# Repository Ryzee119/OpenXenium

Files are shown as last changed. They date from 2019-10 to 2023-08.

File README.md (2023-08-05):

# OpenXenium
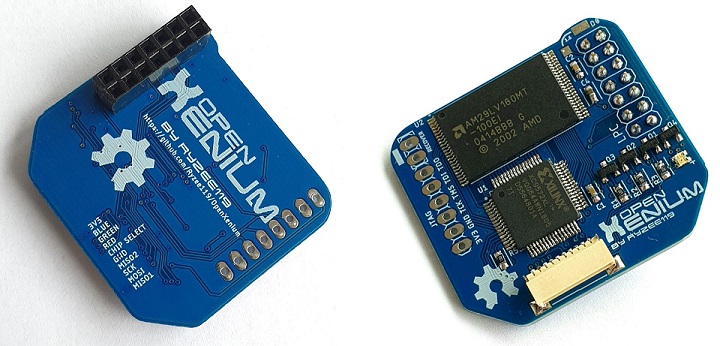
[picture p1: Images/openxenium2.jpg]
OpenXenium Assembled

## About this Repository
This is an open source recreation of an Original Xbox LPC memory/IO device. Generally known as a *modchip*.
The VHDL is 100% compatible with XeniumOS, which is a legal non-Microsoft based bootloader made by TeamXodus for the Original Xbox. This allows loading user BIOS binaries and some basic Xbox tools (EEPROM Backup/modification, Hard drive Rebuilding, Locking, Unlocking, FTP access).  
  
The VHDL written by Team Xodus was never released and the CPLD is read protected so it is not trivial to extract the bitstream.
My own VHDL is probably quite similar to what Team Xodus produced for the Xenium Modchip but I have independently reverse engineered the behavioral design on the CPLD. (There was no bypassing of the protection features of a genuine Xenium.) Therefore I have named this project **OpenXenium**. *An open source recreation of the Xenium CPLD released under GPL which documents the internal workings by means of open source VHDL of the Xenium Modchip*.

I do a quick run through of the build process here: https://youtu.be/P6YYViKby74

To manage your OpenXenium device's flash memory, the Xenium-Tools homebrew program has been moved [here](https://github.com/Ryzee119/Xenium-Tools).

## Supported Features
The VHDL implements the following LPC transactions:
  * Memory Read/Writes (Translated to a parallel flash memory interface)
  * IO Read/Writes

From an Original Xbox perspective, this covers all requirements to make a custom LPC memory/IO peripheral for the console. Colloquially known as a *modchip* which can load custom BIOS files like Cromwell and its derivatives without modifying the onboard TSOP flash memory or softmodding. This supports IO control for accessories like LCD screens, LED controllers, external switches etc.

When used with XeniumOS the VHDL in this repo supports the following features:
  * Software controlled BIOS bank switching (any BIOS combinations that fit into 1mbyte of flash memory (4x256k, 1x512+2x256k, 2x512k, 1x1mbyte).
  * Instant boot to a chosen BIOS using the power button.
  * Boot the XeniumOS with eject button.
  * Ability to boot from the onboard BIOS (colloquially known as TSOP booting). This will completely disable OpenXenium and release D0/LFRAME(1.6) to boot the Xbox as if stock.
  * All the standard features in XeniumOS. (EEPROM tools, Hard drive tools, FTP/SMB Server etc.).
  * Three general purpose outputs. These are normally bitbanged as a SPI master (MOSI,CLK,CS) with the most common use an LCD, however could support any SPI peripheral in theory.
  * Two general purpose inputs. On a Xenium, these are I believe intended to be MISO lines to complement the SPI interface but could be used for any 3.3V digital logic.  
  * Three outputs are connected to an RGB led (Or an external user added RGB led).
  * Reserved memory on the flash chip for non-volatile storage of an EEPROM backup and XeniumOS settings.
  * If you bridge the two recovery pins on power up, it will attempt to boot the XeniumOS recovery BIOS if available. This functions the same as a genuine Xenium modchip.
  * I also simulate the LFRAME abort mechanism (*Ref Intel LPC Interface Spec Rev 1.1 Section 4.2.1.13*) so that this will work on a v1.6 Original Xbox. This aborts the LPC transaction to prevent the Xyclops responding to the MCPX LPC Memory Read requests during boot (and conflicting with an external LPC memory peripheral). This is generally accepted to be better than shorting LFRAME the ground constantly which some traditional *Modchips* do.

## XeniumOS BIOS
**The recommended way to get a copy of XeniumOS is to take a backup of your own Xenium modchip using [Xenium-Tools](https://github.com/Ryzee119/Xenium-Tools/releases).** It is also possible to parse the v2.3.1 XeniumOS update files released by Team Xodus to extract the neccessary data; however this will not contain the factory programmed recovery sector, but otherwise works in the same way.

This has been tested with XeniumOS 2.3.1 (Last release) and XeniumOS 2.3.1(Gold variant). The only way to obtain Gold OS is to dump the flash contents of your XeniumGold as the binary files were never distributed individually.

## Installation and Initial Setup
See [Installation.MD](https://github.com/Ryzee119/OpenXenium/blob/master/INSTALLATION.md)
## Licensing
OpenXenium is free and open source. Please respect the licenses available in their respective folders.
  *  Hardware is shared under the [CERN OHL version 1.2.](https://ohwr.org/cernohl).
  *  Firmware is shared under [GPLv3](https://www.gnu.org/licenses/quick-guide-gplv3.en.html).
  *  xenium-tools was made with [NXDK](https://github.com/XboxDev/nxdk) and is shared under [GPLv2](https://www.gnu.org/licenses/old-licenses/gpl-2.0.en.html).
## References that helped me in this project
  * [Intel LPC Spec](https://www.intel.com/content/dam/www/program/design/us/en/documents/low-pin-count-interface-specification.pdf)
  *  [NXDK](https://github.com/XboxDev/nxdk)  
  * [AladdinLCD  Github Repo (CPLD LCD Driver)](https://github.com/Ryzee119/AladdinLCD)
  * [LPC Analyser Plugin](https://github.com/Ryzee119/LPCAnalyzer)  
  * [Deconstructing the Xbox Boot ROM](https://mborgerson.com/deconstructing-the-xbox-boot-rom/)

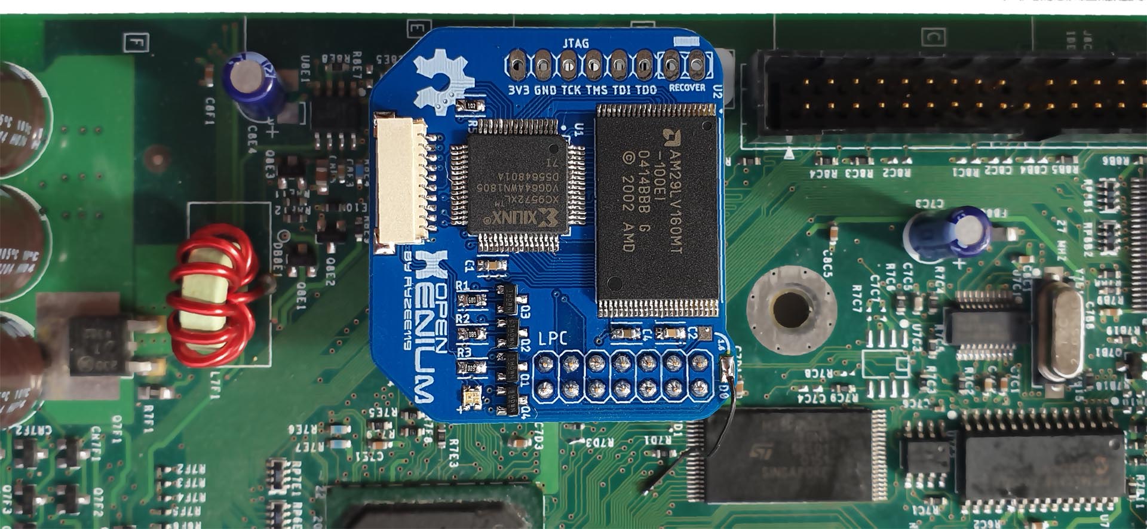
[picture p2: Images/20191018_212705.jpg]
Open Xenium Installed


If you like my work please consider a small donation<br>
<br>
By Ryzee119

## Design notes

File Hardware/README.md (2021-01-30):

# OpenXenium PCB.
* This board was designed using [Autodesk Eagle](https://www.autodesk.com/products/eagle/overview). You can edit the `.brd` and `.sch` with this program.
* You can easily order the PCB and components (DIY soldering) via KitSpace: https://kitspace.org/boards/github.com/ryzee119/openxenium/.

## Schematic and Gerbers
See [Releases](https://github.com/Ryzee119/OpenXenium/releases).

## Bill of Materials
See [bom.csv](../.kitspace/bom.csv).

## High Res Assembled Photo
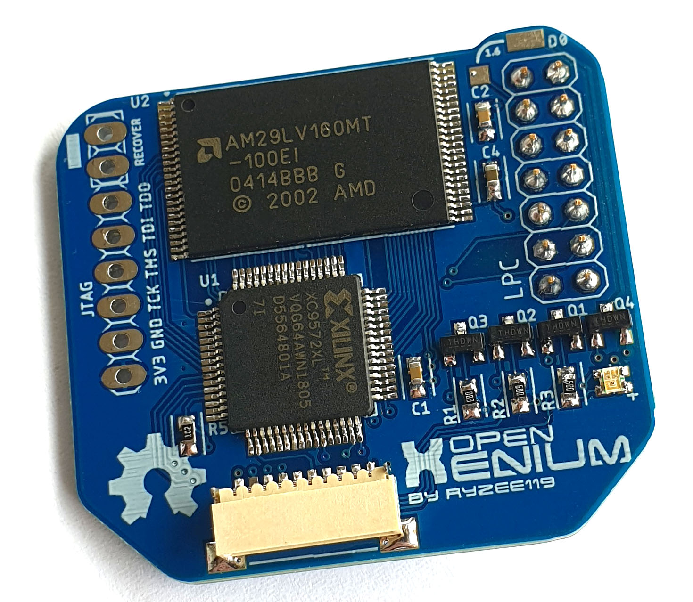
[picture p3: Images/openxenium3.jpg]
High Res Photo

By Ryzee119

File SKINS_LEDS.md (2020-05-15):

# XeniumOS Skins and LED Patterns
XeniumOS supports custom skins and LED PWM patterns. The PWM test patterns are only persistent within XeniumOS so aren't particularly useful, however are documented here anyway.
 * Skins should be placed in their own subdirectories at `\E\XeniumOS\Skins\`
 * LED scripts should be placed in `\E\XeniumOS\LEDs\`

## Skins
Skins require a 640x480 jpg file named `backdrop.jpg` with an associated `Skin.cfg`.  
`Skin.cfg` configures the colour of the text, and menu objects etc. These lines represent a six digit HEX colour value.
The comments in this example are provided for clarity only and **must** be removed before attempting to load the skin in XeniumOS.<br><br>
An example might look like this:

```
9abcde //Text Box - Text Colour
9abcde //Text Box - Background Colour
9abcde //Text Box - Border Colour 
9abcde //Text Box - Text Selection Highlight Colour
9abcde //Menus - Text Colour
9abcde //Menus - Text Selection Highlight Colour
9abcde //File Explorer - Background Colour
80     //Top Menu - X Position
153    //Top Menu - Y Position
300    //Top Menu - Width
256    //Top Menu - Height
8      //Top Menu - No. Items to Display

```
 See the `releases` section for an example skin I put together:
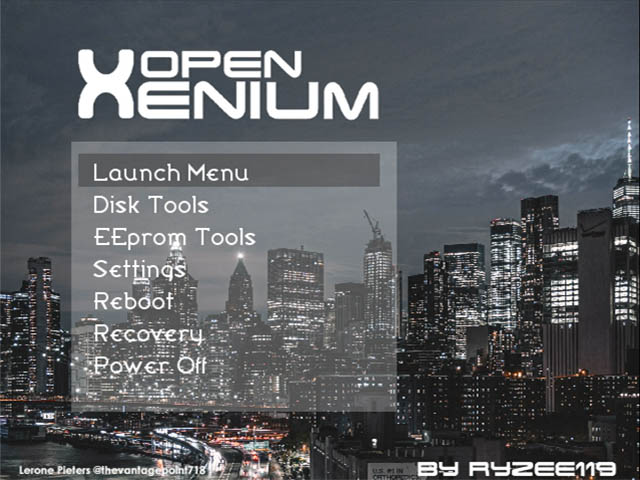
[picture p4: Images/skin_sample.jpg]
   
If you would like me to add your custom skin, please ensure it uses royalty free art work with appropriate credits as required by the author.
## LED PWM Patterns
LED test patterns have the file extension `led`.
A [quote from TeamXodus on the format](https://www.xbox-hq.com/html/article1577.html)

> The format of these files is straightforward; each line in the file represents one set of the leds. The first number is the duration for this set, the second number represents the color to set on the chip LED (0-7), and the third number is a standard hexadecimal representation of the front-panel LED.

An example of a single line might be  
`40 1 0f` where:  
`40 = duration (milliseconds?), 1 = RED, 0x0F = green eject led (0xF0 = red eject led)`

You can find a program called [XeniumOS LED Designer 1.1](https://www.xbox-hq.com/html/downloadview-details-953-XeniumOS_LED_Designer_v1.1.html) online which can assist in creating these patterns.

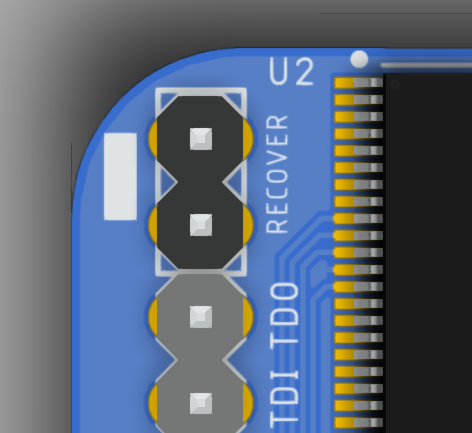
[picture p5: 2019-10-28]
Images/recovery.png

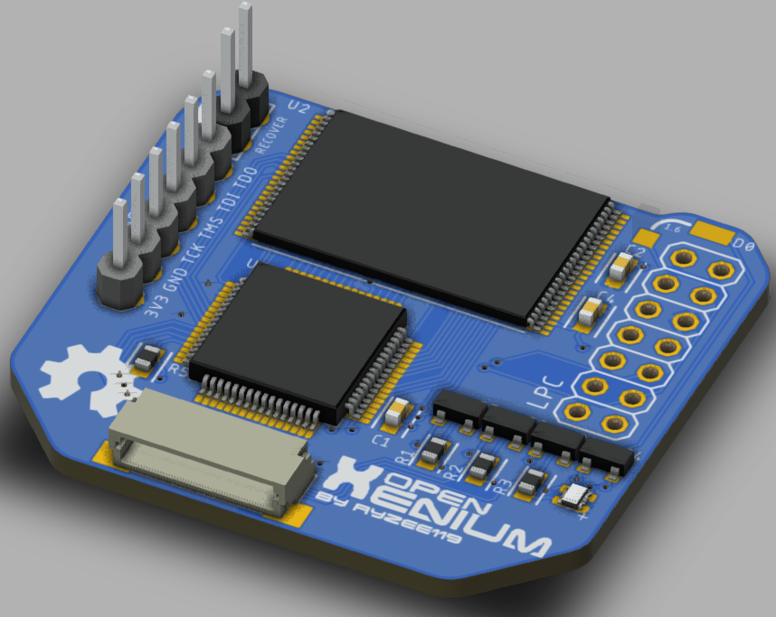
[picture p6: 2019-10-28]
Images/render.PNG

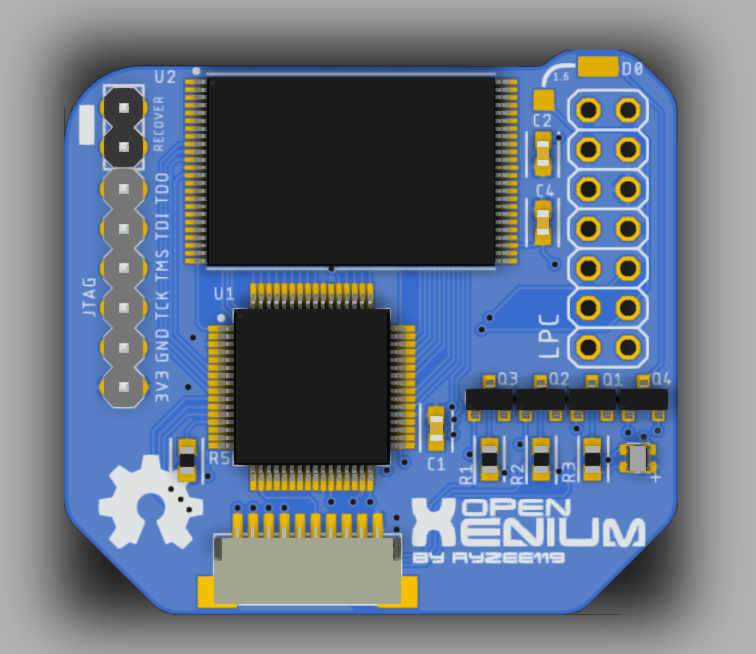
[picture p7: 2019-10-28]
Images/rendertop.PNG

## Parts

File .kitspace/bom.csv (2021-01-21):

Reference | Qty | Description | Part Number | Manufacturer | Digikey
U1 | 1 | IC CPLD 72MC 10NS 64VQFP | XC9572XL-10VQG64C | Xilinx Inc. | 122-1388-ND
U2 | 1 | 16MBIT PARALLEL FLASH MEMORY 48TSOP | AM29LV160MT-100EI (legacy) or S29AL016J70TFI010 | Cypress Semiconductor Corp | 1274-1013-ND
LED1 | 1 | LED RGB CLEAR 4SMD. COMMON ANODE | 19-237/R6GHBHC-A07/2T | Everlight Electronics Co Ltd | 1080-1590-1-ND
J1 | 1 | JST SM CONN HEADER SMD R/A 10POS 1MM | SM10B-SRSS-TB | JST Sales America Inc. | 455-1810-1-ND
C1,C2 | 10 | CAP CER 0.1UF 50V 0603 | CL10B104KB8NNNC | Capacitor Generic | 1276-1000-1-ND
C4 | 5 | CAP CER 10UF 6.3V 0603 | JMK107ABJ106MA-T | Capacitor Generic | 587-5869-1-ND
R1,R2,R3 | 10 | RES 68 OHM 5% 1/8W 0603 | RK73B1JTTD680J | Resistor Generic | 2019-RK73B1JTTD680JCT-ND
R5 | 5 | RES 1K OHM 5% 1/10W 0603 | RMCF0603JJ1K00 | Resistor Generic | RMCF0603JJ1K00CT-ND
Q1,Q2,Q3,Q4 | 5 | MOSFET N-CH 20V 4.1A SOT-23 | IRLML6246TRPBF | Infineon Technologies | IRLML6246TRPBFCT-ND
LPC | 1 | Female Pin Header | PPTC072LFBN-RC | Female Pin Header Generic 2x7 0.1in | S7075-ND

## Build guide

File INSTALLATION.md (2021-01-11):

# Installation

## Program CPLD (If building it yourself)
1. To program the CPLD see the [Firmware](./Firmware/README.md). page. Some programming notes are provided below:  
1.1 You will need a good quality JTAG programmer with the ability to parse`.svf` files. Some universal JTAG programming software is `OpenOCD` or `URJtag`. Check these for compatible programmers.  
1.2 The JTAG connection points are located along the edge of the OpenXenium PCB and are clearly labelled on the silkscreen.  
1.3 OpenXenium may require an external 3.3V power supply when programming. The RGB LED should be on when programming.  
1.4 The RGB LED will default to white if the CPLD is unprogrammed and will default to red once programmed.  

## Programming XeniumOS to OpenXenium (If building it yourself)
1. Confirm that the CPLD is programmed as per the above section.
2. Boot your Xbox using another bootable modchip and transfer `default.xbe` from [Xenium-Tools repo](https://github.com/Ryzee119/Xenium-Tools/releases) to your xbox. You must boot the Xbox using another modchip. Booting from the onboard TSOP will prevent xenium-tools from working.
3. Transfer over a xenium 2MB raw `flash.bin` **or** XeniumOS 2.3.1 `recovery.bin` (v2.3.1 only) to the xenium-tools directory.  `flash.bin` is full Xenium flash memory dump obtained from a Genuine Xenium device using xenium-tools (Menu option START+X). This is the recommended file to use as it contains the recovery sector which allows the recovery feature to work on an OpenXenium. 
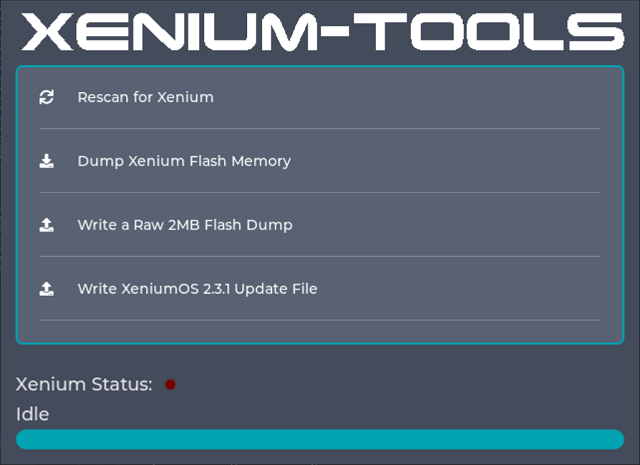
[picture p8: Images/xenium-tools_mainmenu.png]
xtools main menu
4. Open the Xenium-Tools xbe. The main menu looks like this <br> 
5. At the main menu, carefully remove the current modchip and replace it with an OpenXenium. Hotswapping is not ideal and so great care should be taken to not drop anything into the Xbox and triple checking pin header alignment before commiting to pushing it onto the header.
6. Select `Rescan for Xenium` to confirm it can detect your OpenXenium. If this doesn't work, confirm you have programmed the CPLD with the OpenXenium firmware (RGB LED should default to red) and you have installed it correctly on the header.
7. Selected  `Write a Raw 2MB Flash Dump` or `Write XeniumOS 2.3.1 Update` accordingly.
8. Confirm no errors are shown.

## OpenXenium Installation in Xbox
1. The following steps assume you have an assembled OpenXenium and have programmed the CPLD and programmed XeniumOS as per the above sections.
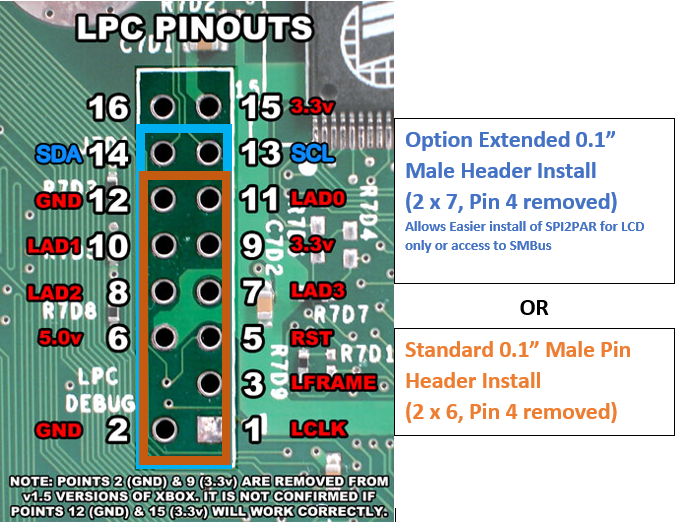
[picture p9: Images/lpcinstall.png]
2. Install a 7x2 or a 6x2 pin header in the LPC port of your Xbox console.OpenXenium has two extra header pins that purely bring the SDA and SCL pins up to the PCB for easier installation of a [spi2par2019](https://github.com/Ryzee119/spi2par2019) or access to the SMBus data lines. These are completely optional, just be mindful of the pin alignment when you install the OpenXenium onto the header though. <br>
Pin header soldered in place
4. For a **1.6 Xbox** you will need to rebuild the LPC. This can be achieved by manually rewiring using 30AWG solid core wire, or using a LPC rebuild PCB. See below for wiring: <br> LPC Wiring
5. For a **non v1.6** Xbox connect the Xbox motherboard D0 point to the OpenXenium's D0 pad. If you decide to connect the motherboard D0 to ground directly the *Boot From TSOP* feature in XeniumOS will not work.
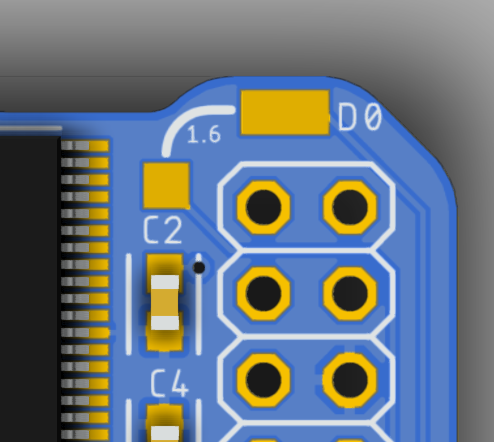
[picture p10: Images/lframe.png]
Open Xenium D0 Point
6. For a **1.6 Xbox** bridge the OpenXenium D0 pad to the nearby 1.6 solder pad on the OpenXenium PCB as per the silk screen markings. See the image below for the location of where the wire bridge should go: It is marked '1.6' on the OpenXenium PCB. <br>

Example installation on a non-1.6 motherboard with the motherboard's D0 line soldered to the OpenXenium's D0 pad.
OpenXenium example installation

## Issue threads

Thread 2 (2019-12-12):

1.6 XeniumOS graphical issue

Ryzee119, 2019-12-12:
On some 1.6 consoles when booting into XeniumOS, there is a graphical issue which results in vertical lines across the screen.

It is suspected this is a bug in Cromwell's Xcalibur or GPU initialization code. This issue is present on my Genuine Xenium and my OpenXenium boards running XeniumOS v2.3.1.

There have been instances of a reflow of the LPC resolving this issue but it is unclear what the root cause is.

No functionality is impacted and once booted into a 1.6 compatible bios the issues is no longer present.

Ryzee119, 2019-12-12:
Example image
![Uploading JPEG_20191009_202012.jpg…]()

johngeffe, 2019-12-13:
Yours is much more pronounced than the 1.6 I did last night (thanks for the help).

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

Ryzee119, 2019-12-13:
I done some more testing and XeniumOS 2.0.0 and 2.2.1 do not have this issue.
Until I work out a fix, this is a potential work around if the bars annoy you.

The downgrade process is generally pretty simple, but do at your own risk:
1. Download the XeniumOS v2.0.0 or v2.2.1 update files released by Xodus.
2. Place `recovery.bin` at the root of the E partition
3. Turn off the Xbox.
4. Bridge the two recovery pads on the OpenXenium and press the power button
5. The recovery procedure should begin. Just wait untill the process is complete and the xbox should turn off automatically. (Do not turn off the Xbox manually during this process)
6. Press Eject to reboot into XeniumOS.
7. Let me know if this resolved your issue.

Ryzee119, 2019-12-15:
I can fix it if I push new register values into Xcalibur.
I can use my own Xcalibur dumps taken after running older versions of XeniumOS or the values from Cromwell. Now just need a way to fix the binary

Ryzee119, 2019-12-17:
Anyone can try this to see if it fixed their issue. However, this is purely a hacky hardware fix that temporarily fixes the issue. It will restore to the default broken values each reboot.
https://github.com/Ryzee119/XcaliburInjector

jkammueller, 2020-02-26:
Any chance this can be implemented in hardware on the mod chip itself so it auto injects every time on startup? I presume a separate firmware and circuit may be required for such a feat. Correct?

Ryzee119, 2020-02-26:
The chip itself is not capable of doing it. The CPLD is too limited unfortunately.

https://github.com/Ryzee119/XcaliburInjector i guess is already a hardware mod in a way. The code could be modified slightly so that it detects XeniumOS is running and auto injects the values seemlessly.

nelsonra911, 2021-03-11:
Just ran into this issue on a 1.6. Any updates on whether this will be merged into a future OS version?

charj, 2021-04-13:
Also experiencing this one freshly installed modchip on a 1.6 xbox

iamaldovanucci, 2021-06-20:
The issue was cleared up for me by installing 2.2.1. Really appreciate the suggestion!

iamaldovanucci, 2021-07-20:
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

Here is a picture of what my 1.6 motherboard with xeniumos 2.2.1 looks like. I've got three of them and on my display they all look the same.

How does it compare to yours? Can you post pictures?

GreenHawk2021, 2021-07-22:
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
I solved the problem! It was the component cable, with composite it is colored and with 2.3.1 it is normal without vertical stripes.

tuxuser, 2021-11-23:
V1.6 gfx issue is fixed with an unofficial fw update: https://github.com/MakeMHz/xenium-fw-update

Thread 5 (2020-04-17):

not really an issue

arnoz26, 2020-04-17:
Hi !
JLCPCB made a mistake and send me 100 of your PCB for your openxenium project...
Do you need them (i'm in france)

Just send me a message arnoz      @       arnoz      .     com

Ryzee119, 2020-04-29:
Thank you for your generous offer. I already have plenty (and im in australia so shipping is probably not cost effective.
Good luck with your builds

Closed 2020-04-29.

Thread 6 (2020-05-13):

v1.0 Xboxes 'frag' when booting Cromwell/Xblast from XeniumOS

Ryzee119, 2020-05-13:
There appears to be an incompatibility with XeniumOS and Cromwell that is specific to version 1.0 Xboxes. Im yet to see a report with another version Xbox.

When attempting to boot Cromwell or its derivatives (Such as XblastOS) on a 1.0 Xbox via OpenXenium the xbox will frag  (Flashing Red And Green eject button).

This is a known issue as far back as 2004 (From https://tinymicros.com/wiki/Gentoo_Linux_On_An_Xbox)
`
VERY IMPORTANT: As of 2004/10/27, v1.0 Xboxen with Xenium ICEs can only use Cromwell BIOS 2.30 and BELOW. This limits you to using 2.4 verison(sic) kernels. Cromwell 2.31 and higher changed the memory map so that 2.6(sic) BIOSs can be be used. The problem with the Xenium on v1.0 boxes is believed to be a CPLD issue. The problem shows up when trying to start the 2.31+ BIOS. The box will power cycle twice, and then FRAG (Flashing Red And Green eject button). This may or may not be fixable. If you have a v1.1 or higher XBox, you won't have to concern yourself with this issue.
`

It claims it could be a CPLD issue, but I believe its an issue with Cromwell initialization being incompatible with XeniumOS previous initialization which causes some a conflict.

Workaround is to use Cromwell 2.30 or below.

GXTX, 2021-01-02:
Just a guess but I think Xcalibur stuff is what broke it, between 2.30 and 2.31 that's about all that really changed although there were 40 commits - most being tiny code changes outside init stuff. `2.31: 98cc81d` `2.30: a1b92cf` and Xcal was added in `3bb29b8`.

gaasedelen, 2022-04-09:
I looked at this briefly last spring and I felt pretty confident that the issue was going to stem from when they changed around cromwell's memory layout: https://github.com/XboxDev/cromwell/commit/5702a104b87f1d8ff223b2795e0f813233507fc1

This PR from mike also felt relevant: https://github.com/XboxDev/cromwell/pull/53

It suggests that Cromwell probably took an accidental dependency on some cached CPU state (or MCPX 1.0 artifacts) that get blown away by the fact that OpenXenium always boots into an XOS stub first.

I'm kind of looking back at some XOS stuff for fun, so I'll drop any other related notes here if I think they're useful.

gaasedelen, 2022-10-06:
Just to follow up, I did investigate this awhile back (at least for XBlast) and I don't really think there's anything that can be done on the OX side.

The reason XBlast does not boot off an OX on 1.0 consoles is because of how strict the timing threshold was on the SMC challenges for 1.0 hardware. On 1.0 consoles the SMC must receive correct responses to the retail SMC challenges within ~125ms of power on. XBlast booting off OX does not complete them till ~150ms (based on what I traced on a scope).

Maybe the xenium CPLD logic for address translation / fetching from the flash is a 'bit' slower than dumber modchips, slowing down the XBlast boot just enough to fall outside the acceptable threshold to complete the SMC challenges.

Really, I would argue this is more of an XBlast issue than an OX issue. This is because XBlast first copies the entire 'OS' (~140kb) from flash into RAM before bothering to complete the SMC challenges... and this is particularly slow over LPC.

https://github.com/ldotsfan/lpcmod_os/blob/96e6a95912fb236c5d8c263d2e5836645df9c140/boot_rom/2bBootStartup.S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

IMO the correct solution is that XBlast should perform the challenges in its bootloader before it copies its OS from flash to RAM. This is what the Microsoft bios' do (prior do decrypt, and decompression of the kernel), and basically every other scene bios.

Maybe it's possible that the Xenium CPLD logic could be 'improved' to speed up the flash addressing or w/e but I'm not totally convinced. But I'm not sure it's worth it tbh. Most people use XBlast only to test RAM upgrades, which would require OX xcodes to also be modified to support booting with mismatched ram chip numbers.

Anyway, just wanted to post this for context. I'm not sure there's a good fix here, besides both updating XBlast and xenium flash xcodes. But that probably falls outside the scope of this repo.

Ryzee119, 2022-10-06:
Thank for you taking the time to dig into this. I did some what consider challenge response times in development however as I was never able to repeat this during dev I didnt look into it further.

In the CPLD I used 6 wait states for read and writes. I cant't recall exactly why I chose 6, but the access time of the legacy xenium flash chip is 100ns, so the minimum we could get away with a 4 wait states (4x33Mhz ~ 120ns) atleast on paper. I may have encountered issues here to increased it to 6 for good measure.

Modern flash chips OX uses are 70ns, so we could get away with 3 wait states in this instance, but I would want to remain backward compatible.

With 4 wait states we could save ~120ns per nibble. Which could certainly help.

The line is here: https://github.com/Ryzee119/OpenXenium/blob/ddff19542de02756fcfe4f6c8f32b3b8d159e99e/Firmware/openxenium.vhd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

If you have a setup to synthesite and reprogram I could be worth testing, but I would not be able to do this anytime soon.

gaasedelen, 2022-10-06:
Neat, good catch.

I actually do have a VM setup to rebuild the VHD from when I was poking at some stuff a few months back. I can dust it off and test both 3 & 4 wait states this weekend.

I'm calculating that this could save ~9-12ms on XBlast, which *could* be just enough to squeak under the threshold. The spread might have actually been tighter, but I won't hold my breath.

gaasedelen, 2022-10-09:
I just want to confirm that dropping wait states to 4 (even 3) keeps the chip functional but does not resolve the issue. XBlast still does not boot on a 1.0.

I haven't actually taken new measurements with a scope, maybe tomorrow if I have the time I'll hook it up and try comparing a 6 wait state chip versus a 3 (maybe even a 2??) to see what the measured timing differences actually are.

haxar pinged me to say that he added an experimental commit to cromwell based on this discussion which will hopefully rectify it on that front: https://github.com/haxar/cromwell/commit/1a258b1caf1e7e9fa7f8099e74efc1078ff3336d

Ryzee119, 2023-08-05:
Should be fixed by v1.4 and requires the CPLD firmware to be upgraded. I am unable to test as I dont have a v1.0 Xbox so hopefully I get some feedback from some users before closing this issue.

RAM upgrade testing will still not work as XeniumOS cannot be with partial RAM installs.

catogtp, 2023-08-05:
I can confirm that xblast is now booting on a 1.0 after this update. It previously would fail to boot and reset the console loading XOS again. No hiccups and other bioses now seem to init faster and boot up with less noticeable lag.

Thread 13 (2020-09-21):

More than 64mb of RAM but less than 128mb

amerika13, 2020-09-21:
I don't know if this is an issue, a potential feature request or just something I need to deal with, but I installed the Open Xenium chip today and I setup Xblast OS so that I could test RAM chips as I installed them. However, I came to the realization that I didn't set Xblast OS as the default kernel before installing the first chip. My Xbox no longer boots to Open Xenium.

My question is, should it boot regardless of RAM or is that not something it handles?

If it is handled by Open Xenium, I guess I have an issue with my RAM chip installation.

I doubt there is any bypass to boot Xblast OS, but if there is, let me know.

Ryzee119, 2020-09-21:
Setting Xblast as default may have not made any difference anyway because it actually still boots XeniumOS first but then quickly switches bank and restarts seemlessly to give the appearance of direct boot.

Im not aware of how XeniumOS handles RAM over 64MB.

* Try booting with eject button to force XeniumOS.
* Try older XeniumOS versions. For example pre-version 2.0 runs a Cromwell backend so may boot with dodgy ram chips past 64MB. (Although not sure how you can downgrade now, maybe the recovery jumpers could do it with a older recovery.bin burnt to a DVD)

Unfortunately the best bet I think is a go back to a alladdin or something with Xblast or finish the install and hope for the best 👍

amerika13, 2020-09-21:
Thank you for the response and I will be finishing the install and hope for the best haha. I've been metering it out as I go and everything checks out compared to the other factory installed chips for my first chip install.  I'll just repeat that 3 more times and hope things boot 👍

Take care and thank you so much for your efforts on this project as it has already been extremely useful for myself and some others I know who was not aware of it until recently.

amerika13, 2020-09-21:
I closed this, but I would like to add that I finished installing the remaining 3 chips and Open Xenium now boots up just fine. And, of course, I can now get into Xblast OS and test the chips (they tested out good).

So, for at least 1.4 motherboard Xbox's, Open Xenium works with 128MB of ram. Or at least boots up. I haven't gotten to poke around with some of the features. But my guess is that it will be just fine.

Thank you again!

Ryzee119, 2020-09-21:
Thanks for the update. Glad you got it working :)

Closed 2020-09-21.

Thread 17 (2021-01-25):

XeniumOS, Do not set a password

Ryzee119, 2021-01-25:
There's an option is XeniumOS v2.3.1 to enable a password. It lets you turn it on but never asks for a password.
At next boot it will ask you for a password before continuing and it'll be in a boot loop.

If you have a default BIOS, it'll reboot into that dash which gives you a chance fix with Xenium-Tools, otherwise you must be the recovery jumper with `recovery.bin` at the root of  E, or burnt to a DVD.

kaosengr, 2021-02-22:
I believe the password is one that has a fixed value in the firmware.

XWAY - X White A Y

It is not something the user enters.

I found this tidbit of info posted back on 17 Dec 2004 at https://www.elotrolado.net/hilo_nuevo-xenium-os-2-0-2_366733#p1702229880

See the Password Lockout section from the TeamXodus's quoted text below:

Quote

TeamXodus escribió:

2 COOL NEW FEATURES...

And lots of bug fixes in the source tree

Now that we have the bug fixes out of the way, we can concentrate on offering you real fun and tangible stuff that you will enjoy. We are proud to present Xenium XOS 2.1.0.

Although we are starting small and building up to bigger and bigger things we really want you to try these features and tell us what you think. Unlike others who are doing away with features and giving you half the value at half the price we are continually adding to our product to give you double and triple the value at the same great price. Xenium is Premium, simple as that.

Password Lockout:

This is by far our most requested feature since shortly after we first released the concept of an operating system controlled chip onto the world. When both the Password and InstantBoot options are enabled, XeniumOS will not allow you (or little siblings, troublesome cousins, or anyone else) to enter the XeniumOS configuration menus without first entering a system password. There are 2 passwords to start, "XWAY", and the classic Konami code, "UUDDLRLRBAS." This will keep uninformed users away from sensitive configuration menus and utilities.

QuickRegion ™

The second feature was only requested by one person, but we thought it was an excellent suggestion, and very much in keeping with the philosophies of our legal OS. QuickRegion™, when enabled, allows you to select a game region at the touch of a button. ("A" for US/Canada, "X" for Japan, "Y" for Europe/Australia, "B" to keep current setting) An excellent feature if you have a respectable import collection, and are using the chip to allow you to play your legitimately aquired titles from lands afar. With QuickRegion™ you can make your Xbox play any region game in a flash. This cool feature now brings instantaneous power to your fingertips!

Ryzee119, 2021-02-22:
Good find! Ill test it out to see if it works asap

kaosengr, 2021-02-22:
I don't know where they posted that information.  It was not in their
Xenium OS v2.0 User manual.  It must have been on their website back in the
day but the forums and much info were not archivable by the Wayback Machine.

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

--
Kaos Engineer
kaos.engr@gmail.com

Ryzee119, 2021-03-02:
I can confirm they both work. Konami code is trickier to ender as you dont have much time to enter it but it does work :)
Thanks for finding that info!

I'll keep this issue open for visibility

mafredri, 2021-08-18:
In case it interests anyone, looks like @kaosengr was right, it was announced Dec 18 2004 on their website 😄 https://web.archive.org/web/20050106030622/http://www.teamxodus.com/

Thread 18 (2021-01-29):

Schematics not readable for everyone

Teufelchen1, 2021-01-29:
Hi! 🙋‍♀️
Hope your are alright, haven't read you a long time!

I wonder if you could provide the schematics in a more accessible format? Currently it is only provided in a non-free, highly specialised file format. I would love to see some `*.svg` or `*.pdf`.

Typed with love,
Teufelchen

Ryzee119, 2021-01-29:
Not sure I understand exactly. PDF is here:
https://github.com/Ryzee119/OpenXenium/releases

Eagle .sch files also viewable by the free version of Autodesk Eagle.

Teufelchen1, 2021-01-29:
Oh thanks, I just looked inside the repo, not the releases. 😅
You might consider adding the PDF to the repo as `OpenXenium/Hardware/Xenium2019.pdf`(or similar), to ease the next one searching for it.

Ryzee119, 2021-01-30:
Ive added a link in the Hardware readme that points to the releases page where the PDF is located. Hopefully that will help anyone in the future looking for it :)

https://github.com/Ryzee119/OpenXenium/blob/master/Hardware/README.md

Closed 2021-01-30.

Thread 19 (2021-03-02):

Support for Bottom Boot Flash devices

dx4m, 2021-03-02:
Hi, i wanted to ask if it is possible for you to add support for bottom boot flash chips?

I have a bunch of them here, that works normally when reading from it, but writing from the console is the big problem, because of the flipped sectors and the shifted address space.

Like a translation layer between the consoles normal top boot flash sectors and the bottom boot flash sectors. E.g. sector SA34(bottom) == SA0(top), sector SA33(bottom) == SA1(top), etc. And redirecting the addresses for read and write to the specific sectors. So that the CPLD behaves like with a Top Boot Device?

Page 14 and 15 from the [Datasheet](https://datasheet.lcsc.com/szlcsc/2011101105_Cypress-Semicon-S29AL016J70TFI020_C914935.pdf).

greez.

Ryzee119, 2021-03-02:
Hi,
The CPLD is at 100% capacity so translation layers like this are not possible at add.

Unfortunately you will need to use the correct flash chip.

dx4m, 2021-03-02:
Oh, that's a bummer. Never worked with CPLD's in the past, so the only way to implement such thing would be use of a FPGA instead of a CPLD?

Nevermind, I had them on hand so I thought it would be possible.

I've ordered the right ones now from Mouser with a heavy shipping cost. LCSC, where I order all my components, doesn't have them in stock.

Ryzee119, 2021-03-05:
The proper fix would be the modify XeniumOS to support different flash chips, unfortunately due to the source code never being released these types of changes are very difficult :(

Closed 2021-03-05.

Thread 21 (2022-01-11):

Potential replacement for Spansion S29AL016J

Dolnor, 2022-01-11:
Hiya,

I think it's not a secret there's a global chip shortage. I had foolishly assumed one could just get any TSOP48 parallel chip, like Macronix MX29LV160DBTI, and build away based on that. Realization came very late - there are constants in xenium tools and elsewhere (e.g. xenium-programmer) that look for 0x01 0xc4 explicitly and thus the hardware is not classed as a xenium device.

Do we have something remotely similar to S29AL016J readily (albeit at a higher cost) available these days? Farnell has Spansion chips on preorder due late March 2022, Digikey barely has any, looking more likey they actually don't.

Ryzee119, 2022-01-11:
The chip IDs is the first issue, recent analysis of XeniumOS shows it also reads the full chip CFI (presumably with additional checks beyong the chip IDs), also this chip has some unique bank sizing at the end of the flash area, which might be common, but certainly not as common as fixed bank sizes.

Finding the S29AL series chip which looks like it is identical to the original Xenium flash chip rebadged was very lucky. If you find anything else please let me know.

Other chips would likely need extensive patching of XeniumOS

Dolnor, 2022-01-11:
I see, so even worse than I had imagined.

The aforementioned Macronix (Manufacturer:194, Device:73) does enable the chip boot into XeniumOS, but it's verry intermittent. The OS allow the BIOS banks to be added and removed and set default, the banks can be booted no problem and everything in the dash/kernel works, but unpon first reboot something corrupts in memory and the console just starts fragging, until the power is disconnected and the console is booted again via the eject button. Rinse and repeat ..

Ryzee119, 2022-01-11:
Im surprised it gets that far to be honest. Ill check out the datasheet

Ernegien, 2022-01-11:
Sounds a lot like the self-destruct routines in XeniumOS where it wipes the flash when it doesn't detect the proper hardware IDs. LoveMHz has done [some work](https://github.com/MakeMHz/xenium-fw-update) on this, perhaps it's worth attempting to use one of his patched images as a test.

Dolnor, 2022-01-11:
Tampering with a 1.6 console, thats something I came across alright. The prebuilt xbe is unfortunately also checking for valid flash IDs, so booting to it wasn't a problem, getting XeniumOS actually updated before it corrupts was. I don't have toolchain/nxdk setup to pack that check out of it.

I will see if I can figure out how to grab just the bootloader & xeniumos payloads from assets and program them to the chip.

Ryzee119, 2022-01-12:
@Ernegien yep good point, this sounds alot like that.

Dolnor, 2022-01-12:
One thing I forgot to mention - it actually physically ejects the drive before XeniumOS is started. The drive tray persists ejected while you navigate around, which I thought was strange behavior.

As for the experiment to see if self-destruct checks (based on chip info?) have been patched out - in short, that resulted in a big fat nothing. Noticed the const _patch_xeniumos_ is not actually used anywhere in the code, but thought I'd replace that bank anyway, whilst also replacing the bootloader payload at 0x180000 with _patch_bootloader_. The chip comes on, the LED turns blue, then off and nothing happens, no image on screen, nada. Figured, I'll do just the bootloader bank then - same thing. Looking at the LoveMHz code, I don't see any CRC adjustments to the flash contents, just a byte-for-byte write so it's not likely a direct overwrite of the respective payload in the 2Mb file being flashed to the MX chip has a bad checksum somewhere?

After such failure the aforementioned limbo condition still ensues where the console starts fragging, Not sure if there are any other banks in those 2Mb of XeniumOS that also have some form of self-destruct code. But alas, it looks like this is a no-go.

Dolnor, 2022-01-12:
The only chip that seems to be available (at least here) that matches vendor/device IDs of 0x01/0xc4 [according to flashrom](https://github.com/jhcloos/flashrom/blob/master/flashchips.h) is S29GL016A90TFIR1, however looking at the datasheet, the sector layout for 016 variant lists 38 sectors opposed to 34 on original hardware, due to bottom sectors all being 8/4 Kbytes, opposed to varying size.

Now delving into the technical side of this, I recon the memory I ended up with, MX29LV160D**B**TI, is supposed to be a suitable replacement for the legacy AM29LV160MB, which is in fact Bottom Boot .. so far from ideal just from that side of things alone.

Dolnor, 2022-01-12:
According to [this](https://s1.dtsheet.com/store/data/001273371.pdf?key=19e601f660b64ea1889a06db66c12bf5&r=1), the direct replacement for S29AL016J70TFI01 is MX29LV160D**T**TI-70G (damnit, my random choice of components was somewhat close but not quite). Hardware wise, it should be identical, however this doesn't rule out the vendor ID woes, as 0x01 becomes 0xC2 with MX chips. It also doesn't help that MX chips seem to be scarce, too.

Dolnor, 2022-01-12:
I've grabbed a few of the aforementioned top boot MX chips (identical sector layout to the original hardware, except it doesn't implement Secured Silicon Sector), these are unfortunately on back order until late January here, so I'll update the issue if anything changes with the way Xenium behaves using the patched boot code. I have a sneaking suspicion it's the actual software on the memory chip getting corrupted because of effectively flipped sector layout to what the firmware was originally intended for.

LoveMHz, 2022-01-24:
Sorry that it's taken me so so long to notice this issue.

The current patch on xenium-fw-update only patches out one of the checks. The additional 'post boot' self-destruct check is only patched in the last batch of OpenXenium we made and I haven't had a chance yet to update the repo.

If the sector layout is different then there are going to be problems. (Secured sectors support shouldn't be an issue though since it's not used afaik). The plan for us moving forwards is to identify a compatible part and work on the needed patches. (Open source of course).

Unfortunately, I don't have an answer today, but it's on my to-do list.

Dolnor, 2022-01-24:
Thanks for chining in with the details on the patches!

I actually have the XboxHDMI+ order sitting at the post office, waiting to be picked up (they have most ridiculous business hours). Although not sure the Xenium it comes with is the "last batch" as it got shipped some time mid December, I will dump the chip 2MB contents and see what is the bank payload like, i.e. stock blue or indeed has the patches in.

Both S92GL (somewhat wrong sector map) Spanion chips and the MX top boot (idrntical sector map) chips are still not in me hands, so no update on that front.

Dolnor, 2022-01-29:
The Open Xenium I had received with my HD+ order turned out to have bog standard blue OS flashed to it (presumably produced early Dec 2021), having bank CRC32 checksums of 0x0A3D160A and 0x1CF10F96, respectively. When I get the MX chips, it'd be grant if @LoveMHz could provide a raw dump from a recent batch of chips, having the checks patched out, to see how it behaves on a non-native hardware.
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
Dolnor, 2022-06-17:
No worries. May well post it here how you get on.

P.S. This was quite a surreal moment having closed the topic and watching someone stumble upon it whilst livestreaming mere minutes later haha

ComputerBooter, 2022-06-17:
Your telling me haha I refreshed the page to re-read and I was like “oh, he literally posted 15 minutes ago lol what are the chances” amazing. I’ll update here as well

Sent from my iPhone

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

xboxnutter, 2022-06-17:
Oh, great stuff Dolnor, well done.

So what's the procedure to program the MX29LV160DTTI-70G then? Update a regular working spansion to Makemhz 2.3.5 and then dump that and use that to program the MX chip?

Thanks again.
Neil.

Dolnor, 2022-06-17:
If you already have access to a working OpenXenium with a config chip proper, that would be a path of least resistance. The only thing you'd then need to do would be either rebuild xenium-programmer to accept the 0xC2 (Macronix) vendor ID or amend the same thing in Xenium-Tools and rebuild that, so that either could treat the MX make chip as valid hardware when programming XOS binary.

xboxnutter, 2022-06-17:
Ok, thanks for that.

xboxnutter, 2022-06-17:
Any chance of an upload of the Xenium-Tools with the 0xC2 patch ID applied and compiled as I'm on a MAC :o)

Dolnor, 2022-06-17:
Still at work, the project is sat in my WSL at home .. if I don't forget, I'll put it up somewhere. In the meantime, we may ask @Ryzee119 politely to implement the alt mfg id formally, which probably should cause Xenium-Tools to hide the 'Write XeniumOS 2.3.1 Update File' option if it detects a 0xC2 make as it would otherwise allow the user to instantly fubar the chip, if selected.

The crude way I've amended the code is made the (essentially bool) method returning 1 for detected and 0 for not detected return a uint16 instead, which is then passed through a case switch to see which chip is being used, if any that is valid.

xboxnutter, 2022-06-17:
Yep, either way it would no doubt be appreciated by all trying to save and fix up some consoles.
Many thanks.
Neil.

Dolnor, 2022-06-18:
As promised, [here's ](https://www.mediafire.com/file/75z985h9vauchr4/xenium-tools-extra.zip) the pre-build xbe.

xboxnutter, 2022-06-18:
Superb, many thanks for that, it's appreciated.

xboxnutter, 2022-06-18:
Oh, getting an error trying to expand that zip for some odd reason.

Dolnor, 2022-06-18:
OSX has problem with certain zip specifications. Try The Unarchiver, from memory it was the only software that was able to remedy that.

On a side note, I've got about a dozen built and programmed Xenium chips after this experiment, which I'm willing to sell/ship across Europe. If interested, drop me an email.

xboxnutter, 2022-06-18:
Ah right okay, tried terminal and got another nag "need PK comat v6.3", then tried MacPAR deluxe too.

Downloaded Unarchiver - bingo ! Worked as you said.

I've got some chips, missing the flash, got ripped on alix as usual so was stuck, so hopefully can get a few chips from digikey now tah.

Dolnor, 2022-06-18:
This was more of a PSA rather than a targeted sales pitch haha. Although, I appreciate most people lurking around here are probably interested in building their own hardware rather than purchasing it off of someone else. Just had personal 3 boxes sorted and now left with a pile of chips that could help recoupe the costs of buying random memory chips for this experiment, given the current market prices and lead times..

xboxnutter, 2022-06-18:
You'll have no problem shifting some chips right now, and no doubt recoup your outlay and then some! haha
I dunno, this IC shortage malarky is a disaster really for all kinds of projects really.

A shout out to Dustin as well for removing those self destruct routines as well.
Thanks again,
Neil.

ComputerBooter, 2022-06-19:
Just FYI Digikey had 15 in stock a few days ago and I ordered them all, I went to re-check and now they have 1040 in stock.  If you need some, get them now!

https://www.digikey.com/en/products/detail/cypress-semiconductor-corp/S29AL016J70TFI010/3761535

Dolnor, 2022-06-19:
Cheers for the heads up! Makes you wonder how true the "This product is no longer manufactured and will no longer be stocked once stock is depleted" statement actually is...

Here's hoping it's not like *cough* element14 *cough*, saying they have thousands of this one SKU in stock and then sending you an email thanking you for the order whilst saying the lead time is gonna be 22/12/12...

ComputerBooter, 2022-06-20:
Wow that was quick, all 1000 are sold!! Luckily I got a bunch

Closed 2022-06-17.

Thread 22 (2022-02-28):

Issue with superio when lframe is shorted to d0 point like in a 1.6 install

DobaMuffin, 2022-02-28:
When I tried to use a superio serial board in a 1.6 console with the 1.6 jumper shorted, the superio board refused to work. This went away when the jumper was cut. I'd take a guess that the lframe cancellation for the xyclops rom is also cancelling the calls to the superio board.

Closed 2022-07-22.

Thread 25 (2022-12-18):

FRAG with Hitachi-LG drive connected

CplMadMurdock, 2022-12-18:
Xenium OS boots without a DVD drive, it boots with a Thomson drive, but FRAGs when Hitachi-LG drive connected. FRAG occurs when pressing either eject or power. Hitachi-LG DVD drive thoroughly tested after refurb, on non-modded system, works without issue. This is a 1.6 system.

RobGries, 2022-12-27:
I'm seeing the same thing. It seemed to start happening right around when I updated Xenium to 2.3.5 via https://github.com/MakeMHz/xenium-fw-update.

What version are you running?

CplMadMurdock, 2022-12-27:
Same version.

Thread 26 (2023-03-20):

Program XeniumOS without need for modchipped Xbox

VoxelTek, 2023-03-20:
Hi there,

Is it possible to have a way of programming XeniumOS to the OpenXenium without needing a modchipped Xbox? I want to build one myself from scratch, given that I don't have a modchip and modchip prices are greater than I would like. Building one from scratch would be cheaper, however, impossible if I cannot program XeniumOS onto it without having a modchipped Xbox.

Would it be possible to program the software onto it using something such as an Arduino or Pi Pico?

Kind regards,

VoxelTek

Ryzee119, 2023-03-20:
You have to program the CPLD and the flash chip. These both use common programming methods and can be done anyway you can find.

Here's an example using a rasp pi which first programs the CPLD as a bridge to program the flash chip, then writes the OX firmware to the CPLD. Although it has a full PCB you can wire it up manually.
https://github.com/kooscode/xenium-programmer

VoxelTek, 2023-03-20:
Ah, neat. I didn't know of this. Your guide seemed to imply that the only way to program the flash was using a modded Xbox, but it's nice to know that there's an alternative that's more readily available.

I do really appreciate the existence of this modchip, and I'm looking forward to creating one myself!

Closed 2023-03-20.

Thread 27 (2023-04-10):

Pcbway issue

DecanFrost, 2023-04-10:
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

Pcbway says they can not proceed due to an issue with soldermask *(see pic)

Subject: PCBWay- EQ of order W539954AS2D1_OpenXenium-ddff195-gerbers

Hi,
There is a engineering question of order W539954AS2D1.
As shown, the spacing between IC pad is only 0.12mm, we can not do the solder mask bridge.
Please check is it ok to do whole opening for this area?

Any suggestions

Thank you

Ryzee119, 2023-10-10:
This is a pcbway limitation not a board issue really. Dont need soldar mask there i guess just makes it harder to solder

Closed 2023-10-10.

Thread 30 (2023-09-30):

1.6 with 128MB RAM unable to boot.

Andr-Zero, 2023-09-30:
I've noticed since using the 1.4 release, the 1.6 boards that I've been upgrading to 128MB RAM are unable to boot. When powering on the console, the LED on the OpenXenium will start it's cycle and stop on solid blue. The front LEDs on the console will be flashing green until powered off.

Long story short, I ended up testing various different chips (Aladdin, Authentic Xenium, X3, X2, & CheapMod). They all seemed to work okay booting the console. I had another OpenXenium on the 1.3 release and decided to test to find out that it loaded XeniumOS just fine.

To verify that it was indeed the 1.4 release causing the issue. I decided to do something sketchy (Don't recommend) of connecting the CS lines while xBlast 0.60 was booting. This showed the RAM install works after getting past the OpenXenium boot process. Then I took the same chip that had 1.4, reflashed to 1.3, and now the console boots reliably.

I'm not sure if this is the case for all 1.6s with RAM upgrades, as I don't remember running into this issues until this week. Maybe I finally ran through my stash of 1.3s, possibly only select 1.6s, or some tolerance thing with the RAM upgrade?

Andr-Zero, 2023-10-02:
Update

I have three 1.6s now that simply wont work with 1.4, I have several that do work...  I would suspect the install, but they are stable on the 1.3 release.

No idea what the differences are. Even tried swapping the RAM from between the ones that have issues and others that don't. No change, the board that had issues still does and the ones that didn't still don't have issues.

Ryzee119, 2023-10-02:
Which flash chips are you using?

Andr-Zero, 2023-10-02:
Samsung. I've tried both "New" and ones harvested from other boards.

Ryzee119, 2023-10-02:
Sorry I mean flash chips on the xenium chip

Andr-Zero, 2023-10-02:
OH! You did say flash! Sorry about that. I have some with the Spansion chips, two with the spec'd AMD, and several with MX brand. Spansion and MX I can reproduce, I can test the AMD chip later this week. (Have those installed in another console in storage).

Thinking the flash access being too slow?

gaasedelen, 2023-10-02:
Just as a datapoint, I tried this on the one 128mb 1.6 I keep on the shelf for testing / edgecases like this and could not reproduce the issue.

I tested with both a 70ns Spansion (per the repo) running OX 2.3.1 and the official 1.4 SVF. I also tested with one of my 55ns Spansion OX running with lower wait states and OX 2.3.5.

> When powering on the console, the LED on the OpenXenium will start it's cycle and stop on solid blue. The front LEDs on the console will be flashing green until powered off.

No video, or hanging without frag (OX or not) on bootup almost always means the CPU faulted (bad data/instructions) mid boot. This is either bad data from the chip or an issue with RAM regions used later in boot / system runtime.

It's almost never an LPC soldering issue because the system would not even get past RAM or SMC challenges (FRAG) if it was not communicating well with the chip. People also seldom flash images with a mostly working bootchain but a borked kernel.

If your OX with the 1.4 SVF is working fine in other systems or boards, then the flash access on the chip is probably fine. That more or less leaves us with this being a RAM issue... It'd be interesting to see how that board performs under more memory intensive operations.

gaasedelen, 2023-10-02:
Also, part of the reason odd boot hangs are more common on 1.6 upgrades is because the power-on memory test of the lower / retail 64mb is woefully inadequate. It's not at all uncommon for people to cause issues to the retail banks which can slip past the red/orange RAM frag claiming "but the 128mb test passes in XBlast!" (which only checks the upper banks) while getting confused when an MS kernel hangs.

It's not to say this couldn't be a software-ish issue. XOS for example does not do RAM training like MS bootchains, but people also do not update any other passives for these 128mb 1.6 upgrades so you're already playing a dangerous game :-P

If there's not an outright soldering issue (continuity != integrity @ 200mhz) I think this is probably another piece of evidence showing how the mod may be pushing these 1.6 boards out of spec, which is why I generally don't recommend doing it.

Andr-Zero, 2023-10-02:
Personally I'm not a fan of stacking RAM chips. However if I'm asked to do so for someone... I don't mind.

I've also learned not to trust xBlast's RAM test. I usually test with a patched version of Halo2, N64 Emulation, and HalfLife 128MB version. Probably better options to test with, these are just the ones I picked and it seems okay? Open to better suggestions for testing. These three consoles that I'm having issues 1.4, have been able to play for hours without problems with 1.3 or any other chip. I've upgraded about 15 or so 1.6 consoles, there are the only three that's given me issues. So a very small sample size. I'm not ruling out a installation issue, or some component out of tolerance. Just mentioned something here since it seems stable with any other combo other than the OX with 1.4.

When I do these upgrades, I do try to cut the CS line to match clock sync in comparison to the stock chips. Not sure if it matters, but it does calm my OCD. I've also been wanting to try to fix the impedance mismatch caused by the stacked chips. That's a bit off topic though...

gaasedelen, 2023-10-02:
To be clear, I'm not calling this a user error. I do think it's an interesting case, so thanks for opening the issue! Obviously OX breaking on certain configurations is not good.

From what I can tell, the CPLD itself is operating correctly. But what is happening is that the faster LPC reads is exposing the corners that were cut in XOS (and its age) or a hardware deficiency on the motherboard.

Ryzee119, 2023-10-03:
Unless your spansion chips are particularly slow ones, they are 70ns access time. On openxenium even with the "faster" speeds its still 4 LPC clocks (~120ns) (TAR1, TAR2 + 2 wait states) which I think from memory is how many the genuine xenium had.

The other change in v1.4 is to do with releasing the bus when its an unknown command. This allows other devices to work in parallel. I'd maybe need to bisect here and isolate with commit specifically is causing it

Ryzee119, 2023-10-03:
Could you try this? Ive just removed the speed change commit but kept the SuperIO compatibility stuff - to help isolate specifically which commit might be causing it
[openxenium_ddff195.zip](https://github.com/Ryzee119/OpenXenium/files/12788860/openxenium_ddff195.zip)

gaasedelen, 2023-10-08:
> Could you try this? Ive just removed the speed change commit but kept the SuperIO compatibility stuff - to help isolate specifically which commit might be causing it [openxenium_ddff195.zip](https://github.com/Ryzee119/OpenXenium/files/12788860/openxenium_ddff195.zip)

FWIW I had my 128mb 1.6 setup with an OX and superio for over a year and it has been fine.
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
gaasedelen, 2023-10-09:
Honestly, I would be very surprised and confused if the breakage you're experiencing are reproducing with only the changes to support SuperIO and not the speed changes. It might be worth double checking you flashed the right SVF, or possibly @Ryzee119 uploaded the wrong SVF?

I have never experienced anything like this, and I've been actively using those SuperIO changes on a lot of boxes since they were committed two years ago.

Ryzee119, 2023-10-10:
Definitely the right file :) imo the lpc bus changes could be conflicting with xcalibur on a 1.6 - which still doesnt explain why the RAM upgrades changes anything.

One thing you could try is to ground LFRAME on the console and see if that changes anything?

HoRnEyDvL, 2023-10-27:
Just as a FYI.
I'm also experiencing the same same thing.
1.6 Xbox
128mb ram Samsung they are all M series.
1.4GHZ CPU upgrade.

Just frags the the console. Tried same chip on other Xbox  works fine. using Aladdin mod-chip console boots and functions with no problem.

Xblast all ram passes the checks.

HoRnEyDvL, 2023-10-27:
@gaasedelen
@Ryzee119

I think the issue is with Xenium-OS instead of the 1.4 update.

Flashing an older version of Xenium-OS v2.3.1 & the console booted no problem at all. Yes we have the graphical issues with 1.6 encoder but yeah.

Any of the newer updates from MM & the console will not boot.

@Andr-Zero , can you give that a shot to prove if it also works for you ?

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

gaasedelen, 2023-10-28:
Just as a datapoint, I tried flashing 2.3.5 to the OX in my 128mb superio 1.6 to test this today and I didn't have any issues/hangs/crashes across a dozen or so boots.

I don't really have any other suggestions on the OX side besides re-testing with a VHD built with only superio, and again with a separate build that only has the speed changes. Alternatively, removing the M chips and replacing them with matching F chips is also something I would recommend testing.

Andr-Zero, 2023-10-29:
@HoRnEyDvL I can test XOS v2.3.1 here in the next few days and report back. I find it interesting that yours is FRAGing, mine would just freeze mid boot.

Andr-Zero, 2023-11-05:
@HoRnEyDvL

Confirm. 2.3.1 does indeed boot fine with the 1.4 CPLD firmware. I also swapped all M chips over the F series and the result is the same.

I also have someone who I sold a chip to having the same issue with a non-1.6, stock ram configuration board. I'm waiting on more info from the buyer before I want to say it's 100% the same issue. Not sure how it would be, though I'm not sure how it is with 1.6s either...

Andr-Zero, 2023-11-07:
Here's the last bit of testing I've done. Really just rehashing what was said on Discord here for continuity on this issue here on Github.

Setup: 1.6 Xbox with 128MB RAM, OpenXenium w/ CPLD firmware 1.4

First test: Booting XOS 2.3.5 with a Xbox2HDMI, Pound cable, Official Component cables, DIY Component cables, and just setting the HD mode on the AVIP connector. All yields the issue described above. OpenXenium LED stuck blue, Power LEDs flashing. XOS version 2.3.1 boots, just has expected graphical glitches, any newer version do not.

Second Test: Same as first test, EXCEPT using a standard AV cable. XOS 2.3.5 boots.

Third Test: Same as the first test, EXCEPT in another Xbox I set the OpenXenium to instant boot a BIOS. Then moved the OpenXenium to the problematic Xbox. Pressing eject to boot into XOS 2.3.5 fails, solid blue on OpenXenium, flashing Power LEDs. Pressing Power to instant boot BIOS, WORKS! It boots as expected directly into the BIOS.

Fourth Test: Removed 64MB of RAM going back to stock configuration on problematic board, CPLD 1.4 firmware, XOS 2.3.5, and using HDMI adapters or Component cables. XOS does not boot. Instant boot does work, same as test #3. Standard AV does boot just as test #2 does.

I now say this is not related to 128MB of RAM on a 1.6. I don't feel this is an OpenXenium issue anymore. Something with CPLD 1.4 Firmware just highlighted some odd quirk with XOS 2.3.2+.

Shall we close this?

HoRnEyDvL, 2023-11-07:
@Andr-Zero I wouldn't close it as it still a pending issue that requires a fix.  Appreciate all the tests you ran I can confirm the same results. I was unable to twat removal of ram but don't wee it having any difference.

Ryzee119, 2023-11-07:
I'd personally close this but raise another place holder 'for information issue that is a summary of the symptoms and causes for visibility for other people. This issue is good but has a lot of noise from troubleshooting. The placeholder issue will be similar to the other issues I have for XeniumOS.

The issue seems to point to community patches which are out of the scope of this project; you may be able to raise an issue on that git page.

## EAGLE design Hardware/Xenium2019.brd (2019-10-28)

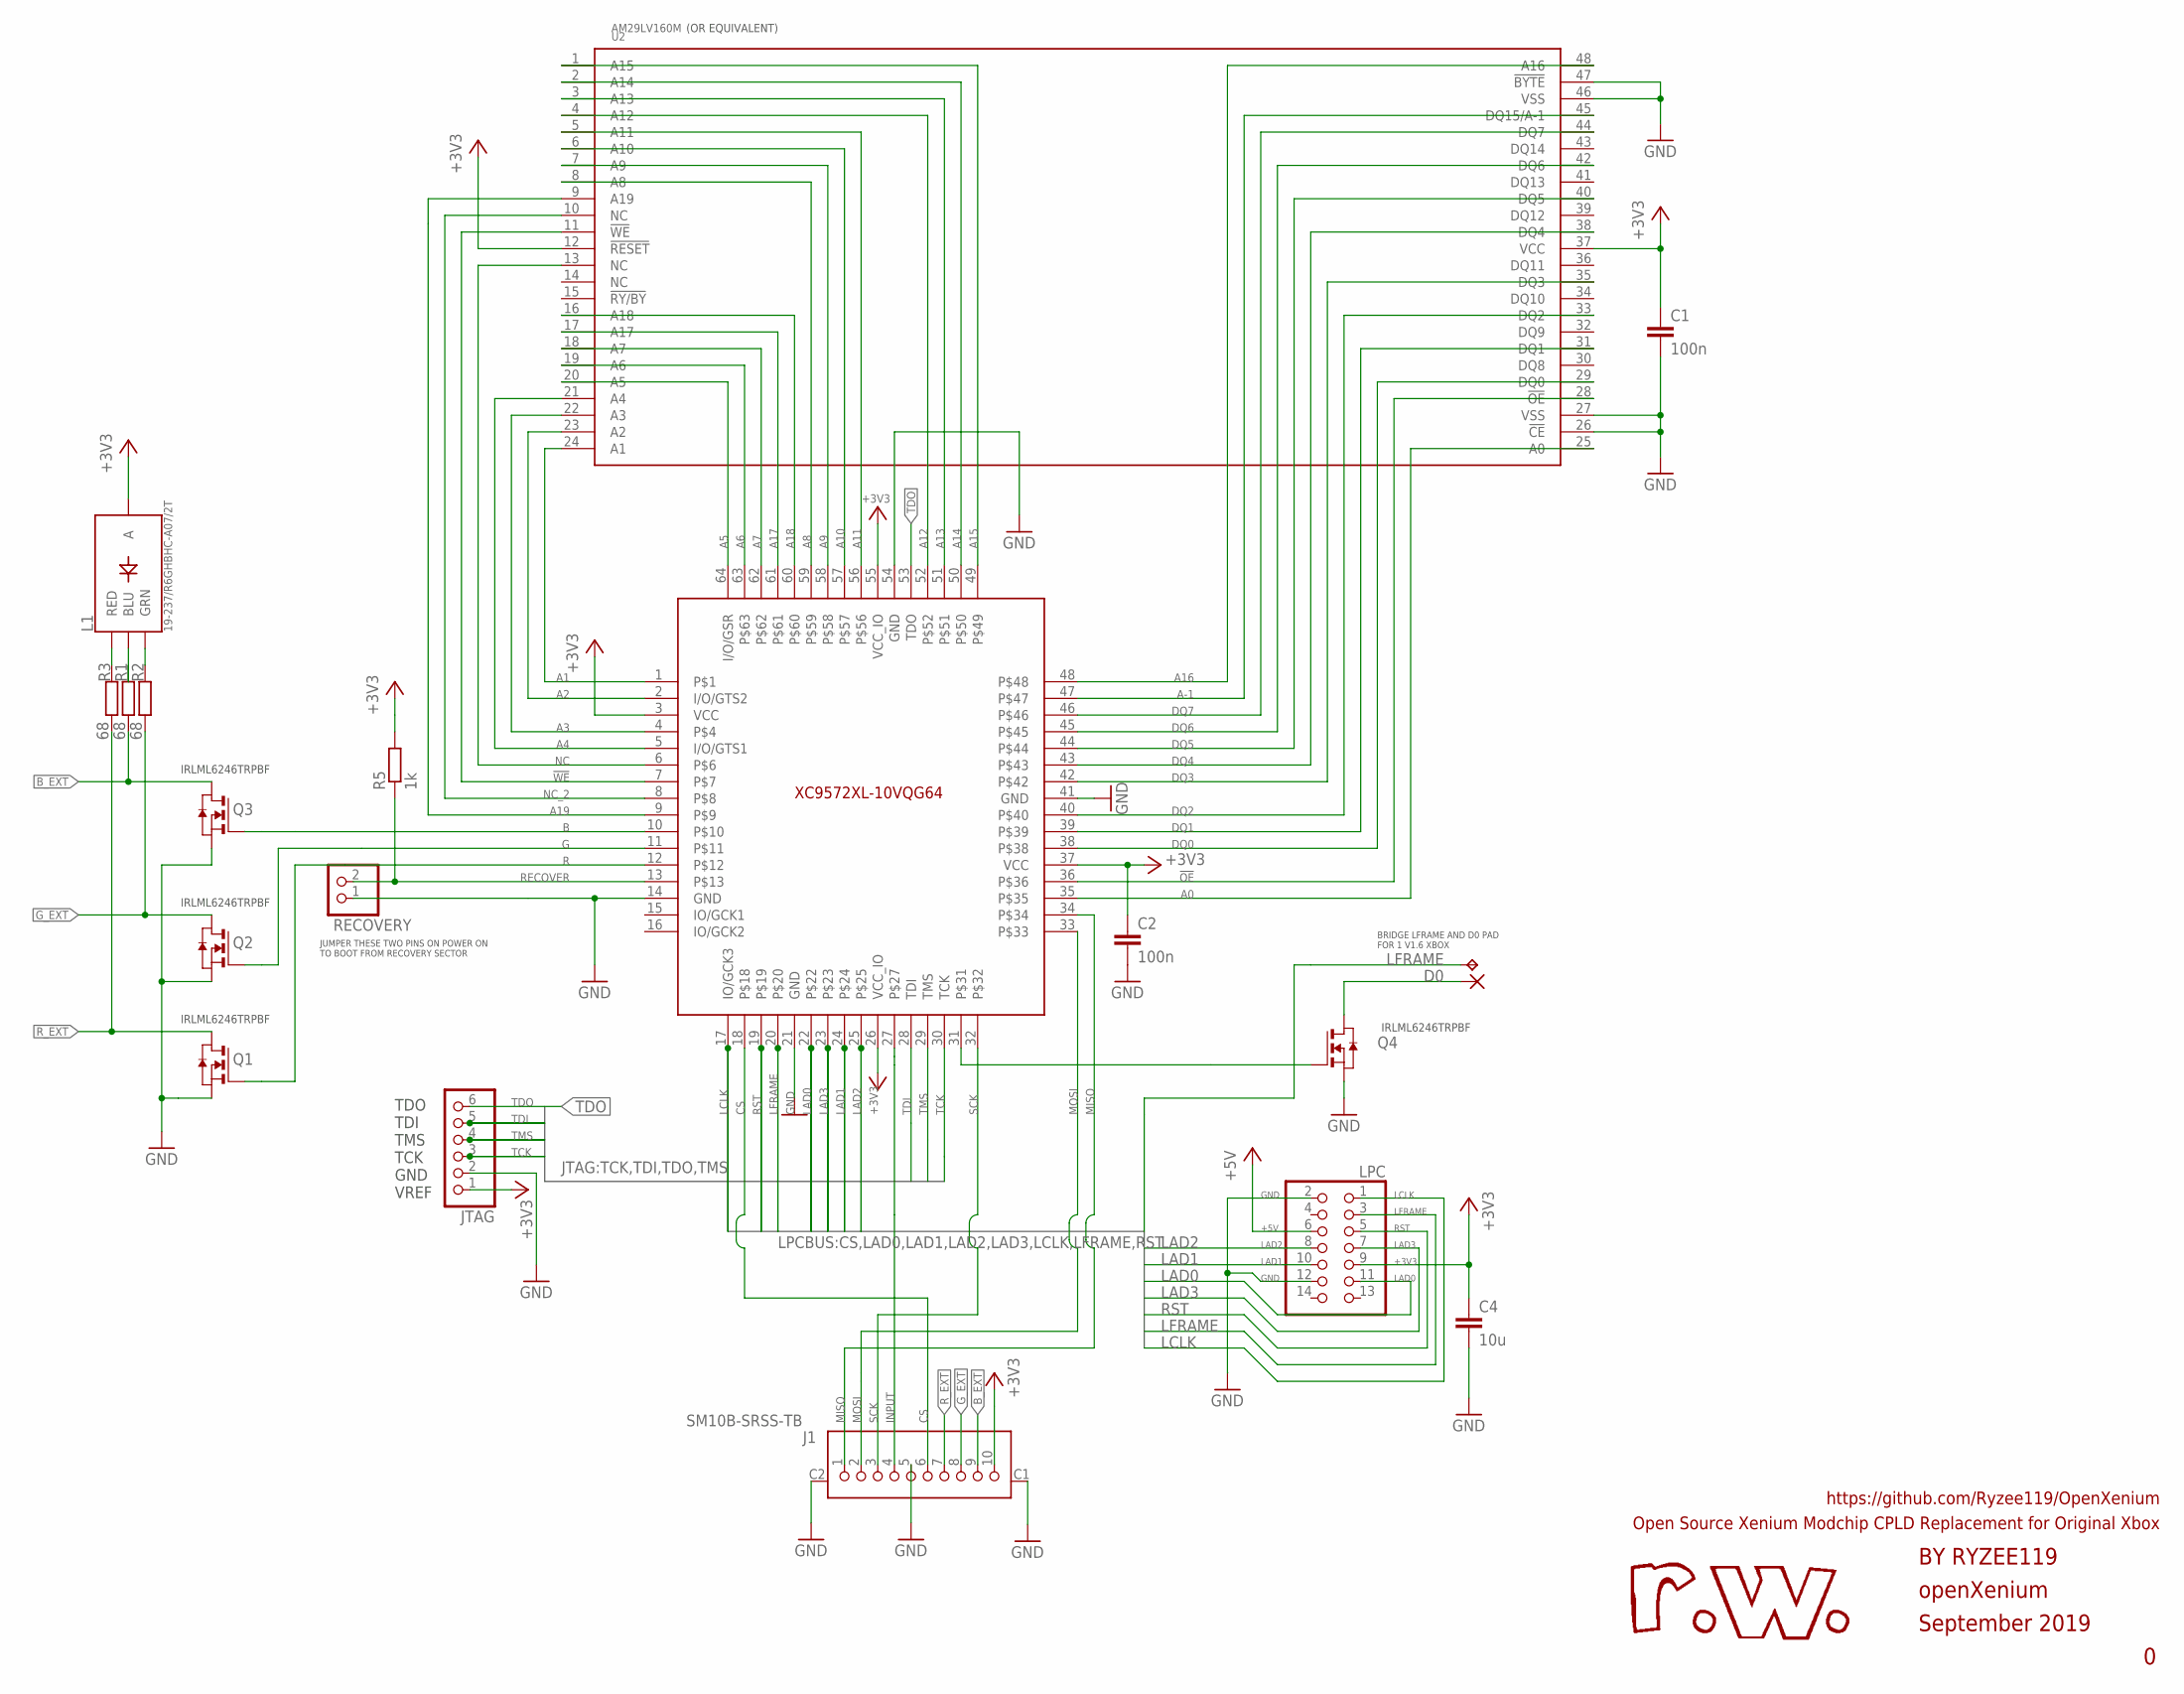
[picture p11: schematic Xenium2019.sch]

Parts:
C1, C2: 100n; C0603
C4: 10u; C0603
D0: SMD2; SMD1,27-2,54
J1: SM10B-SRSS-TB
JTAG: PINHD-1X6; 1X06
L1: 19-237/R6GHBHC-A07/2T; 4-SMD-R6GHBHC
LPC: PINHD-2X7; 2X07
Q1, Q2, Q3, Q4: 310mA/60V/1.6Ω; SOT-23
R1, R2, R3: 68; R0603
R5: 1k; R0603
RECOVERY: PINHD-1X2; 1X02
TP1: TPTP13SQ; TP13SQ
U1: XC9572XL-10VQG64; LQFP64
U2: AM29LV160M; TSOP48

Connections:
!OE: U1.36, U2.28 (!OE)
!WE: U1.7, U2.11 (!WE)
+3V3: C1.1, C2.1, C4.1, J1.10, JTAG.1, L1.P$2 (A), LPC.9, R5.2, U1.3 (VCC), U1.26 (VCC_IO), U1.37 (VCC), U1.55 (VCC_IO), U2.12 (!RESET), U2.37 (VCC)
+5V: LPC.6
A0: U1.35, U2.25 (A0)
A1: U1.1, U2.24 (A1)
A2: U1.2 (I/O/GTS2), U2.23 (A2)
A3: U1.4, U2.22 (A3)
A4: U1.5 (I/O/GTS1), U2.21 (A4)
A5: U1.64 (I/O/GSR), U2.20 (A5)
A6: U1.63, U2.19 (A6)
A7: U1.62, U2.18 (A7)
A8: U1.59, U2.8 (A8)
A9: U1.58, U2.7 (A9)
A10: U1.57, U2.6 (A10)
A11: U1.56, U2.5 (A11)
A12: U1.52, U2.4 (A12)
A13: U1.51, U2.3 (A13)
A14: U1.50, U2.2 (A14)
A15: U1.49, U2.1 (A15)
A16: U1.48, U2.48 (A16)
A17: U1.61, U2.17 (A17)
A18: U1.60, U2.16 (A18)
A19: U1.9, U2.9 (A19)
A-1: U1.47, U2.45 (DQ15/A-1)
B: Q3.3 (G), U1.10
BLUE: L1.P$4 (BLU), R1.1
B_EXT: J1.9, Q3.1 (D), R1.2
CS: J1.6, U1.18
DQ0: U1.38, U2.29 (DQ0)
DQ1: U1.39, U2.31 (DQ1)
DQ2: U1.40, U2.33 (DQ2)
DQ3: U1.42, U2.35 (DQ3)
DQ4: U1.43, U2.38 (DQ4)
DQ5: U1.44, U2.40 (DQ5)
DQ6: U1.45, U2.42 (DQ6)
DQ7: U1.46, U2.44 (DQ7)
G: Q2.3 (G), U1.11
GND: C1.2, C2.2, C4.2, J1.5, J1.C1 (MNT2), J1.C2 (MNT1), JTAG.2, LPC.2, LPC.12, Q1.2 (S), Q2.2 (S), Q3.2 (S), Q4.2 (S), RECOVERY.1, U1.14 (GND), U1.21 (GND), U1.41 (GND), U1.54 (GND), U2.26 (!CE), U2.27 (VSS), U2.46 (VSS), U2.47 (!BYTE)
GREEN: L1.P$3 (GRN), R2.1
G_EXT: J1.8, Q2.1 (D), R2.2
INPUT: J1.4, U1.27
LAD0: LPC.11, U1.22
LAD1: LPC.10, U1.24
LAD2: LPC.8, U1.25
LAD3: LPC.7, U1.23
LCLK: LPC.1, U1.17 (IO/GCK3)
LFRAME: LPC.3, TP1.TP, U1.20
MISO: J1.1, U1.34
MOSI: J1.2, U1.33
unnamed: Q4.3 (G), U1.31
unnamed: D0.1, Q4.1 (D)
NC: U1.6, U2.13 (NC)
NC_2: U1.8, U2.10 (NC)
R: Q1.3 (G), U1.12
RECOVER: R5.1, RECOVERY.2, U1.13
RED: L1.P$1 (RED), R3.1
RST: LPC.5, U1.19
R_EXT: J1.7, Q1.1 (D), R3.2
SCK: J1.3, U1.32
TCK: JTAG.3, U1.30 (TCK)
TDI: JTAG.5, U1.28 (TDI)
TDO: JTAG.6, U1.53 (TDO)
TMS: JTAG.4, U1.29 (TMS)

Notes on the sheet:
TDO TDI TMS TCK GND VREF
openXenium
September 2019
BY RYZEE119
Open Source Xenium Modchip CPLD Replacement for Original Xbox
https://github.com/Ryzee119/OpenXenium
BRIDGE LFRAME AND D0 PAD FOR 1 V1.6 XBOX
JUMPER THESE TWO PINS ON POWER ON TO BOOT FROM RECOVERY SECTOR
IRLML6246TRPBF
(OR EQUIVALENT)

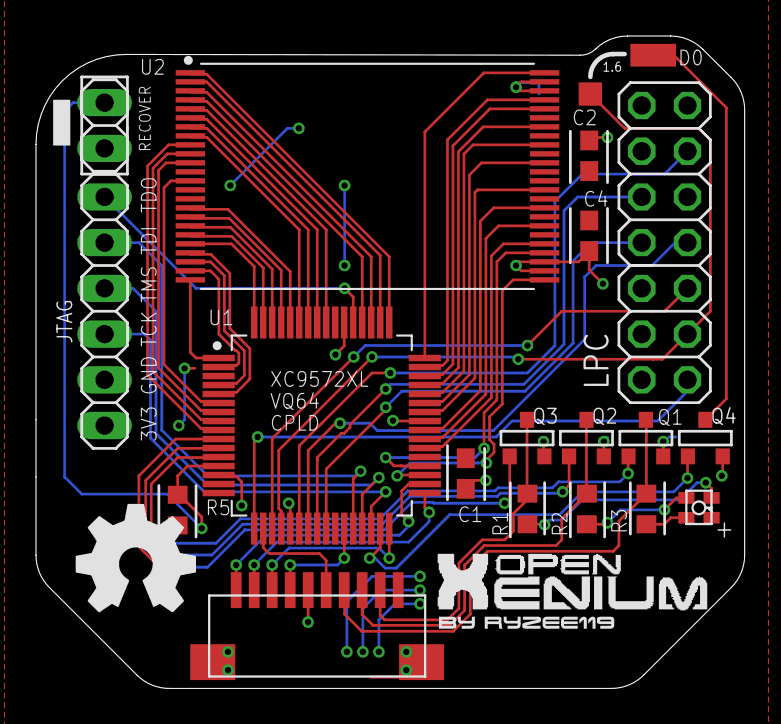
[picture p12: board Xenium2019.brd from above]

Board: 2 copper layers, 39.4 x 36.2 mm, 20 parts (0 on the bottom side), 63 nets.

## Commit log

2019-11-08 Fixed CPLD recovery logic edge case
    [Xenium2019_centroid.csv]
2019-11-08 Fixed recovery logic edge case for CPLD
    [Xenium2019_centroid.csv]
2020-05-14 Updated debugprints for better readability, cleaned up flash driver
2020-08-21 Updated Xilinx ISE instructions
    [bom.csv]
2020-08-23 Add kitspace support
    [bom.csv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]
2020-08-24 Fix bom path in kitspace.yaml
2021-01-21 Bom: Add some spares
    [bom.csv]
2021-01-30 HW: Cleanup readme and link schematic
2021-09-18 Add LPC Peripheral Support
    Prevents openxenium from blocking all other IO reads/writes. This enables other devices to be on the LPC bus at the same time.
    Particularly SuperIO debug modules.
